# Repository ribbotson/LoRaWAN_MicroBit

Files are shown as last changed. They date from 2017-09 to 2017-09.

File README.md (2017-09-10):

# LoRaWAN_MicroBit
This is a free open source LoRaWAN interface for BBC Microbit including power control timer

## Content

This is a hardware project with PCB design file in Eagle. 

## Authors

* **Richard Ibbotson**  

## License

Hardware is Licensed under CERN OHL v.1.2 or later https://www.ohwr.org/documents/294 No warranty is provided for this documentation implied or otherwise.

Software is licensed under MIT License.

MIT License

Copyright (c) 2017 Richard Ibbotson
richard.ibbotson@ribbotson.com

Permission is hereby granted, free of charge, to any person obtaining a copy
of this software and associated documentation files (the "Software"), to deal
in the Software without restriction, including without limitation the rights
to use, copy, modify, merge, publish, distribute, sublicense, and/or sell
copies of the Software, and to permit persons to whom the Software is
furnished to do so, subject to the following conditions:

The above copyright notice and this permission notice shall be included in all
copies or substantial portions of the Software.

THE SOFTWARE IS PROVIDED "AS IS", WITHOUT WARRANTY OF ANY KIND, EXPRESS OR
IMPLIED, INCLUDING BUT NOT LIMITED TO THE WARRANTIES OF MERCHANTABILITY,
FITNESS FOR A PARTICULAR PURPOSE AND NONINFRINGEMENT. IN NO EVENT SHALL THE
AUTHORS OR COPYRIGHT HOLDERS BE LIABLE FOR ANY CLAIM, DAMAGES OR OTHER
LIABILITY, WHETHER IN AN ACTION OF CONTRACT, TORT OR OTHERWISE, ARISING FROM,
OUT OF OR IN CONNECTION WITH THE SOFTWARE OR THE USE OR OTHER DEALINGS IN THE
SOFTWARE.

## Acknowledgments

* All the folks at [rLab](http://www.rlab.org.uk) Reading Hackspace especially mikethebee
+ [Hackaday.io](https://hackaday.io/project/12164-just-do-iot) for featuring the project
+ [The Things Network](https://www.thethingsnetwork.org/)

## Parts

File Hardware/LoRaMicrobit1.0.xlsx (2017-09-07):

MicroBit Lorawan Version 1.0
Bill of Materials
Part | Value | Device | Package | Description | Manufacturer | MPN | Supplier | Supplier Part No
B1 | 2 off AA Alkaline Battery | 2AA Battery Holder | Custom | Battery Holder | Unknown |  | LED Essential | http://www.ebay.co.uk/itm/AA-x-2-Battery-Holder-Box-Case-PCB-Mount-/262350750401
C1 | 12pF | CAP_CERAMIC0603 | 0603 | Ceramic Capacitors | TDK | C1608C0G1H120J080AA | RS | 788-2931
C2 | 10pF | CAP_CERAMIC0603 | 0603 | Ceramic Capacitors | TDK | C1608C0G1H100D080AA | RS | 788-2938
C3 | 100nF | CAP_CERAMIC0603 | 0603 | Ceramic Capacitors | TDK | C1608X8R1E104K080AA | Farnell | 234-6915
C4 | 10uF | CAP_CERAMIC0603 | 0603 | Ceramic Capacitors | Murata | GRM188R60J106KE47D | Farnell | 249-4230
C5 | 1uF | CAP_CERAMIC0603 | 0603 | Ceramic Capacitors | Murata | GRM188R60J105KA01D | Farnell | 952-7699
C6 | 10uF | CAP_CERAMIC0603 | 0603 | Ceramic Capacitors | Murata | GRM188R60J106KE47D | Farnell | 249-4230
C7 | 1uF | CAP_CERAMIC0603 | 0603 | Ceramic Capacitors | Murata | GRM188R60J105KA01D | Farnell | 952-7699
C8 | 100nF | CAP_CERAMIC0603 | 0603 | Ceramic Capacitors | TDK | C1608X8R1E104K080AA | Farnell | 234-6915
C9 | 1uF | CAP_CERAMIC0603 | 0603 | Ceramic Capacitors | Murata | GRM188R60J105KA01D | Farnell | 952-7699
D1 | MBR0520LT | .5A SCHOTTKY DIODE | SOD123 | Schottky Diode | ON Semi | MBR0520LT | Farnell | 253-3224
EC1 | CARDEDGE80 | CARDEDGE80 | CARDEDGE80 | BBC Micro:Bit 80 Pos .05 Connector" | Unknown |  | MDT | http://www.ebay.co.uk/itm/Edge-Connector-BBC-Micro-Bit-Right-Angled-UK-Seller-/182307853730
Q1 | FDN340P | MOSFET-P | SOT23-R | P-Channel Mosfet | Fairchild | FDN340P | RS | 671-0435
Q2 | BSS138 | MOSFET-NREFLOW | SOT23-R | N-Channel Mosfet | NXP | BSS138 | RS | 792-0894
R1 | 100K | RESISTOR0603 | 0603 | Resistors | Vishay | CRCW0603100KFKEA | RS | 678-9673
R2 | 100K | RESISTOR0603 | 0603 | Resistors | Vishay | CRCW0603100KFKEA | RS | 678-9673
R3 | 0R | RESISTOR0603 - NOT FITTED | 0603 | Resistors
R4 | 100K | RESISTOR0603 | 0603 | Resistors | Vishay | CRCW0603100KFKEA | RS | 678-9673
SK1 | I/O Connector | GROVE-CONNECTOR-DIP-90D(4P-2.0) | HW4-2.0-90D | Grove Connector | TAIFENG | HW4-2.0-90D | Seeed Studios | 110990037
SK2 | I2C Connector | GROVE-CONNECTOR-DIP-90D(4P-2.0) | HW4-2.0-90D | Grove Connector | TAIFENG | HW4-2.0-90D | Seeed Studios | 110990037
SW1 | Power On | SPST_TACT-EVQQ2 | EVQ-Q2 | SMT 6mm switch, EVQQ2 series | Panasonic | EVQQ2P03W | RS | 756-1858
U$2 | 0868AT43A0020 | 0868AT43A0020 | 0868AT43A0020 | SMT 868 Antenna | Johanson | 0868AT43A0020E | Farnell | 188-5493
U1 | RN2483 | RADIO MODULE | RN2483 | Lora Transceiver Module | Microchip | RN2483-I/RM101 | RS | 880-6821
U2 | MCP7940N | INTEGRATED CIRCUIT | SOIC8-N_MC | Real Time Clock | Microchip | MCP7940N-I/SN | RS | 798-5258
Y1 | 32.768KHZ | SMD-CRYSTAL-32.768kHz | SMD-3.2X1.5 | Crystal FC135 | Epson | SMD 32.768kHz | RS | 667-6094
S1 | M3 Screw 6mm Long | NYLON SCREW | M3X6
N1 | M3 Nut | NYLON NUT | M3
Richard Ibbotson
Updated 26/10/2016

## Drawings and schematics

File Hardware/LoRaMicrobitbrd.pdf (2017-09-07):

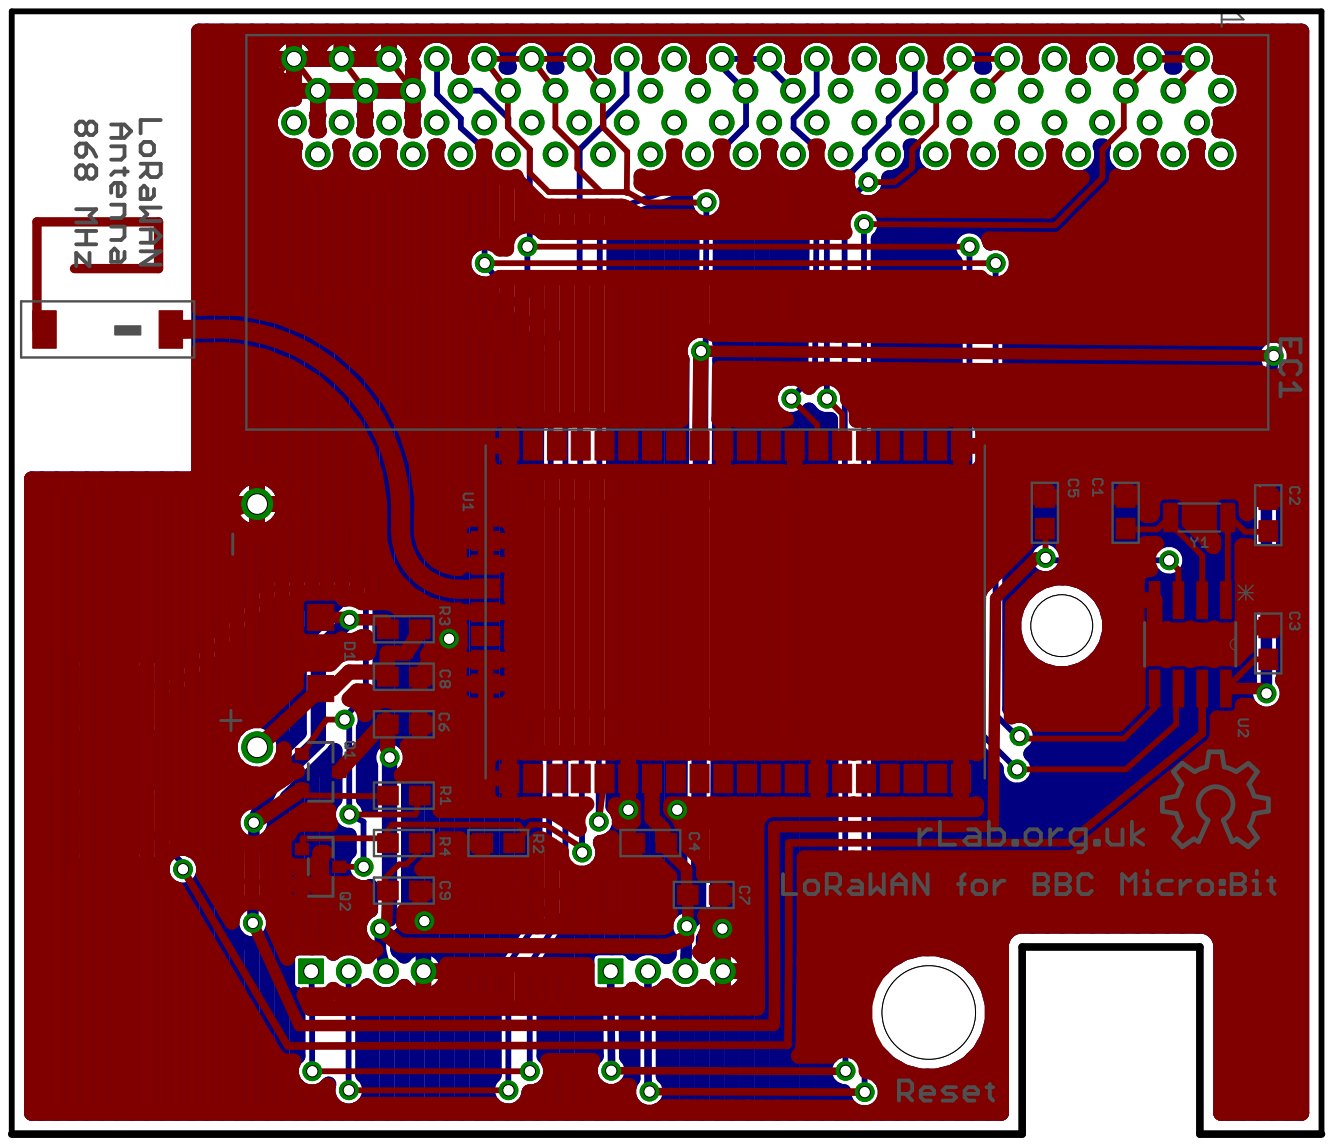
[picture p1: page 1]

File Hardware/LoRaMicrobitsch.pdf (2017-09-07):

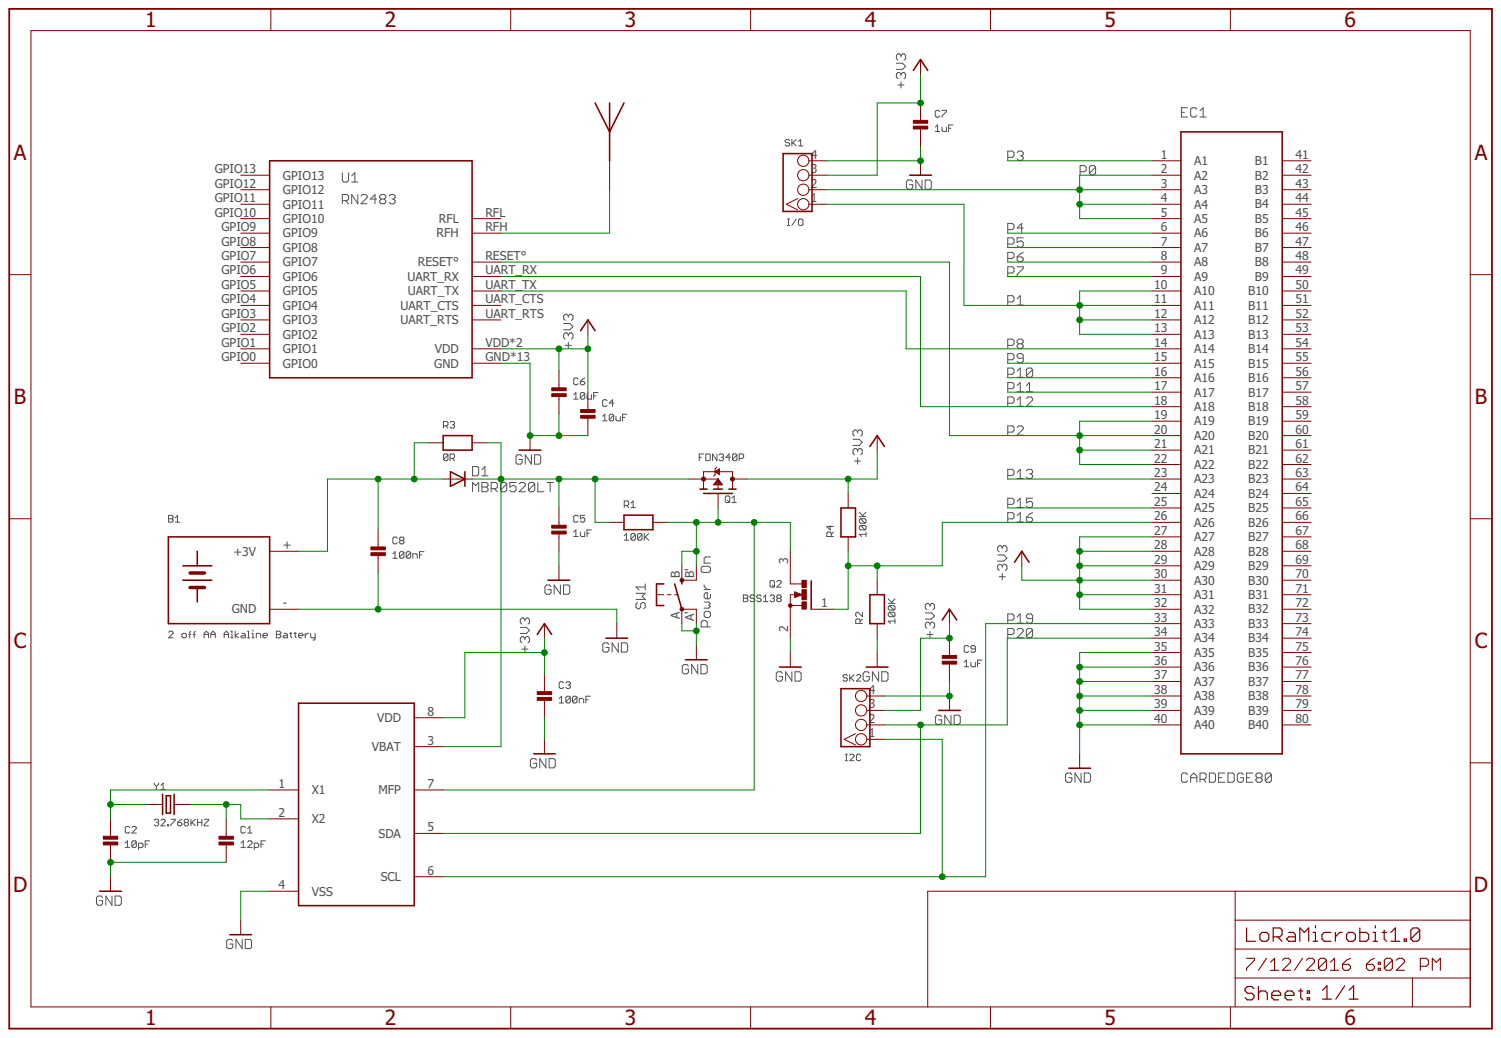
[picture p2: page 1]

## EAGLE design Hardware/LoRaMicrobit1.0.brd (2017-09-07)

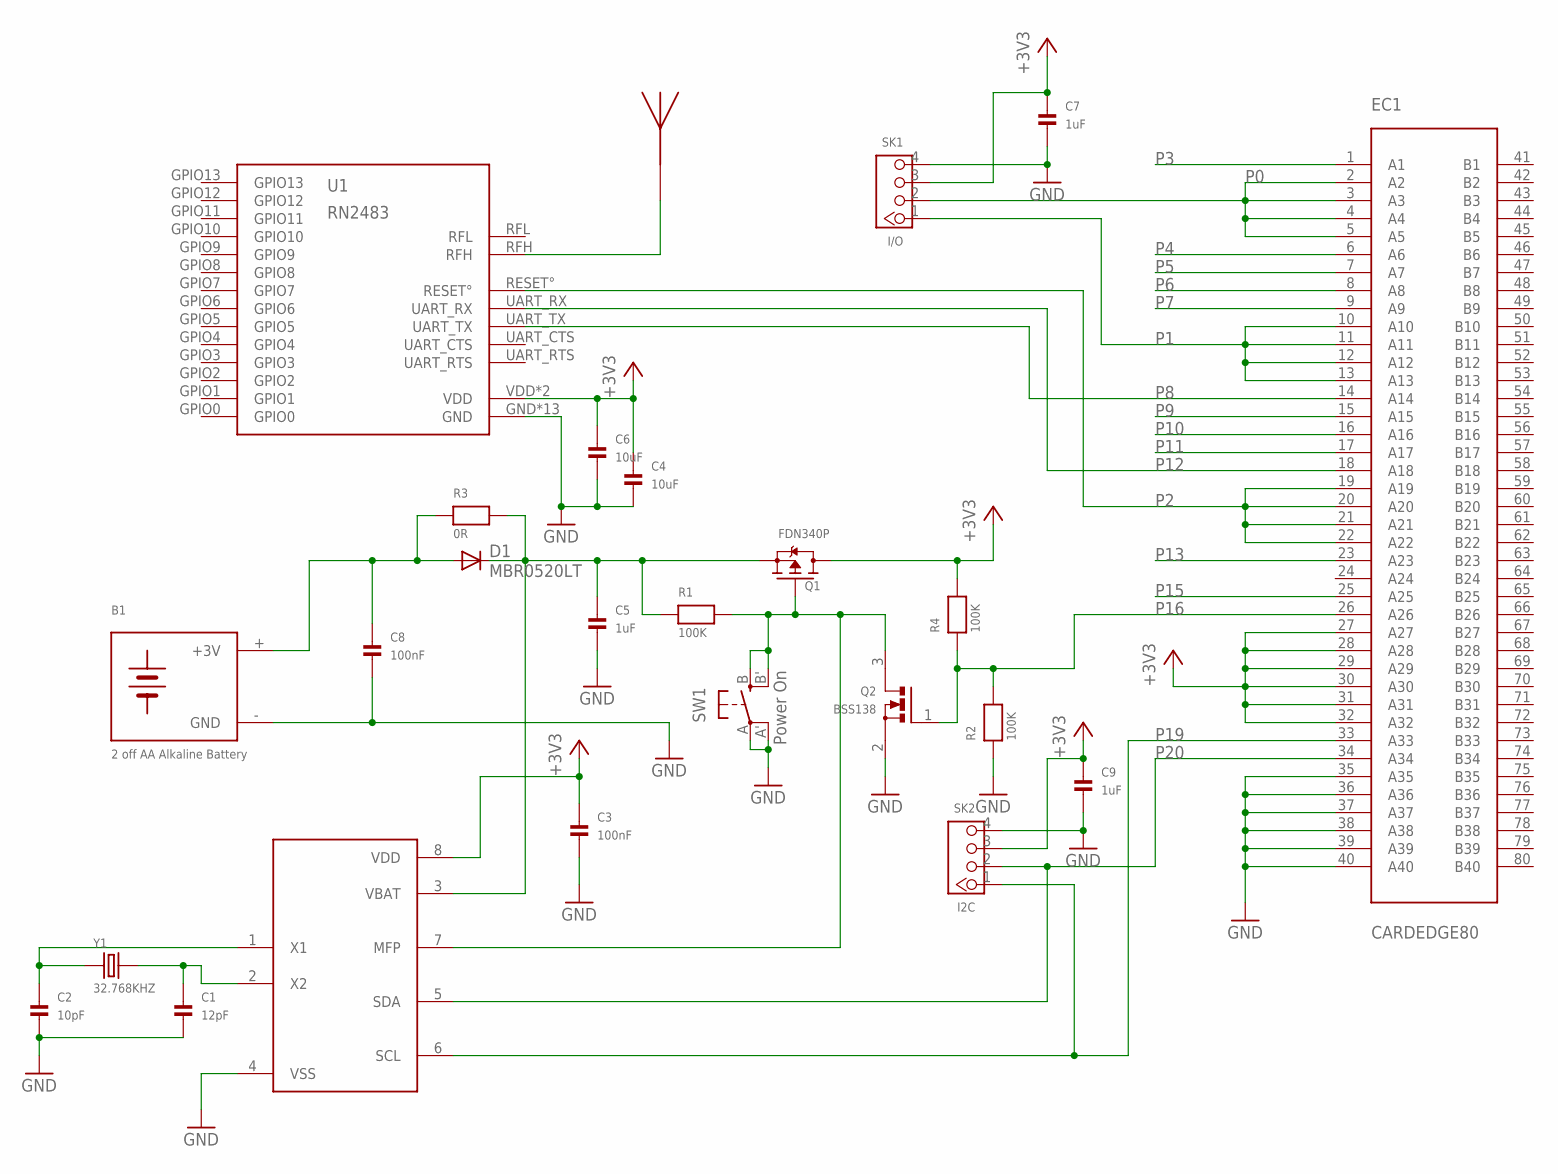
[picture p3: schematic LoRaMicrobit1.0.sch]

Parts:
B1: 2 off AA Alkaline Battery; 2AABATTERY
C1: 12pF; 0603
C2: 10pF; 0603
C3, C8: 100nF; 0603
C4, C6: 10uF; 0603
C5, C7, C9: 1uF; 0603
D1: MBR0520LT; SOD123
EC1: CARDEDGE80
Q1: FDN340P; SOT23-R
Q2: BSS138; SOT23-R
R1, R2, R4: 100K; 0603
R3: 0R; 0603
SK1: I/O; HW4-2.0-90D
SK2: I2C; HW4-2.0-90D
SW1: Power On; EVQ-Q2
U1: RN2483
U2: MCP7940N; SOIC8-N_MC
U$2: 0868AT43A0020; 0868AT043A0020
Y1: 32.768KHZ; X2-SMD-3.2X1.5X0.55MM

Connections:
+3V3: C3.1, C4.1, C6.1, C7.1, C9.1, EC1.27 (A27), EC1.28 (A28), EC1.29 (A29), EC1.30 (A30), EC1.31 (A31), EC1.32 (A32), Q1.3 (D), R4.2, SK1.3, SK2.3, U1.VDD, U1.VDD2 (VDD), U2.8 (VDD)
GND: B1.- (GND), C1.2, C2.2, C3.2, C4.2, C5.2, C6.2, C7.2, C8.2, C9.2, EC1.35 (A35), EC1.36 (A36), EC1.37 (A37), EC1.38 (A38), EC1.39 (A39), EC1.40 (A40), Q2.2 (S), R2.1, SK1.4, SK2.4, SW1.A, SW1.A' (P1), U1.GND, U1.GND1 (GND), U1.GND2 (GND), U1.GND3 (GND), U1.GND4 (GND), U1.GND5 (GND), U1.GND6 (GND), U1.GND7 (GND), U1.GND8 (GND), U1.GND9 (GND), U1.GND10 (GND), U1.GND11 (GND), U1.GND12 (GND), U2.4 (VSS)
unnamed: U1.RFH, U$2.P$1
unnamed: C2.1, U2.1 (X1), Y1.1
unnamed: C1.1, U2.2 (X2), Y1.2
unnamed: B1.+ (+3V), C8.1, D1.A, R3.1
unnamed: C5.1, D1.C, Q1.2 (S), R1.1, R3.2, U2.3 (VBAT)
unnamed: Q1.1 (G), Q2.3 (D), R1.2, SW1.B (S), SW1.B' (S1), U2.7 (MFP)
P0: EC1.2 (A2), EC1.3 (A3), EC1.4 (A4), EC1.5 (A5), SK1.2
P1: EC1.10 (A10), EC1.11 (A11), EC1.12 (A12), EC1.13 (A13), SK1.1
P2: EC1.19 (A19), EC1.20 (A20), EC1.21 (A21), EC1.22 (A22), U1.RESET°
P3: EC1.1 (A1)
P4: EC1.6 (A6)
P5: EC1.7 (A7)
P6: EC1.8 (A8)
P7: EC1.9 (A9)
P8: EC1.14 (A14), U1.UART_TX
P9: EC1.15 (A15)
P10: EC1.16 (A16)
P11: EC1.17 (A17)
P12: EC1.18 (A18), U1.UART_RX
P13: EC1.23 (A23)
P15: EC1.25 (A25)
P16: EC1.26 (A26), Q2.1 (G), R2.2, R4.1
P19: EC1.33 (A33), SK2.1, U2.6 (SCL)
P20: EC1.34 (A34), SK2.2, U2.5 (SDA)

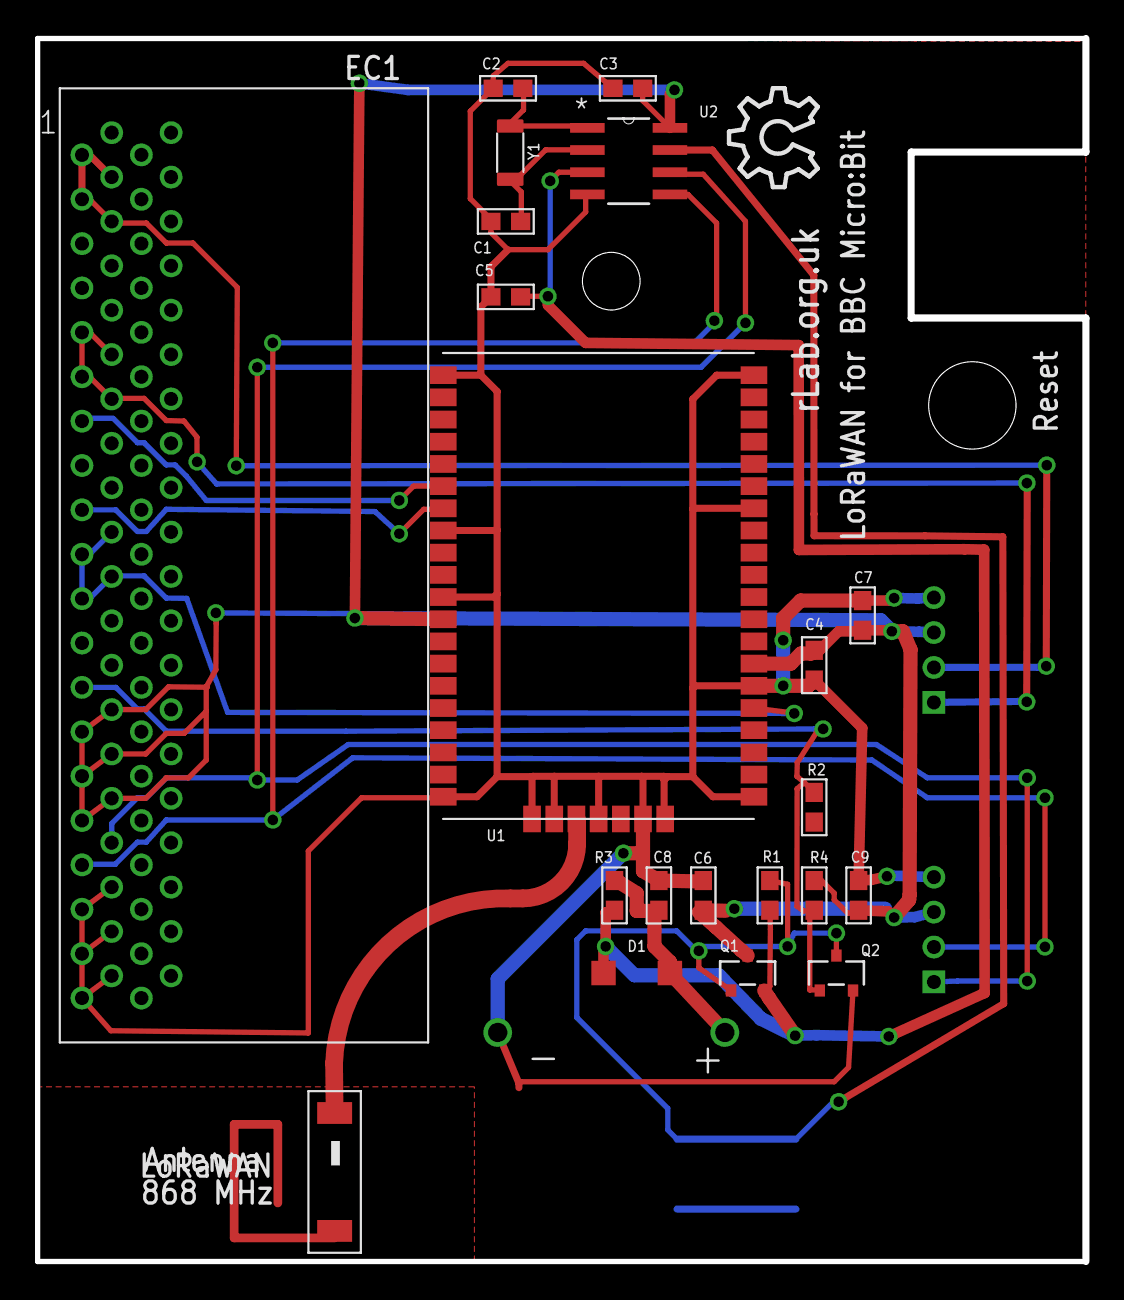
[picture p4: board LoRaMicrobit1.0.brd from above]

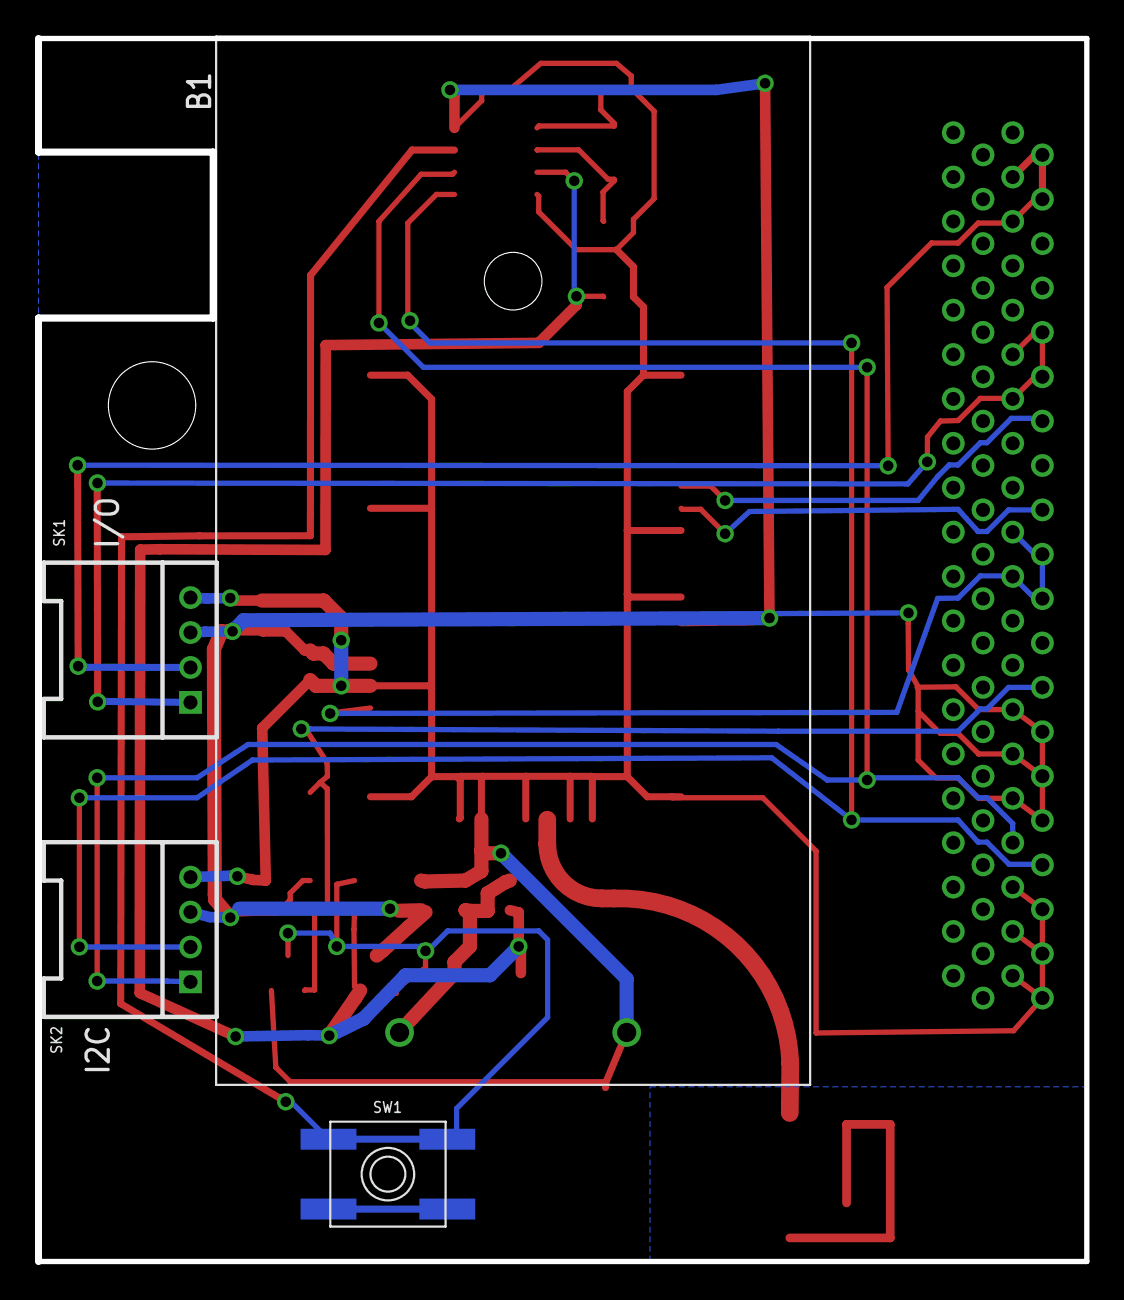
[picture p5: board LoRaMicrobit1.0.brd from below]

Board: 2 copper layers, 60.0 x 70.0 mm, 26 parts (4 on the bottom side), 16 nets.

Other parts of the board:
U$1: OSHW_10X200_NOTEXT

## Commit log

2016-07-22 LoRaWAN for Micro:Bit
    [LoRaMicrobit1.0.brd, LoRaMicrobit1.0.sch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]
2017-09-07 Minor layout change to avoid reset witch
    [LoRaMicrobit1.0.brd, LoRaMicrobit1.0.xlsx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]

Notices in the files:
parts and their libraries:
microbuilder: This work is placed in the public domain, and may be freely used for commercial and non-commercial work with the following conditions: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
